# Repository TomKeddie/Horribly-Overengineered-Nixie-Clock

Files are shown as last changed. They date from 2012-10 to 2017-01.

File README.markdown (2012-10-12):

# Horribly Overengineered Nixie Clock

This is a "horribly overengineered" Nixie clock as the "clock" part could have been achieved far cheaper
and far easier. However, the end result (that there is an actual physical clock) is merely a side effect;
the main motivation for me was to use this project as means to learn something new. To this end, I've used
a fairly expensive ARM microcontroller and the mainboard also includes both USB and Ethernet connectivity.

There are two PCBs in this project: a driver board housing two Nixie tubes with their corresponding drivers
and a mainboard with the uC and other circuitry. The driver board is designed to fit into the 5x5 cm limit
and the mainboard fits the 5x10 cm limit of ITead Studio/Seeed Studio. A full kit with 6 digits would consist
of one mainboard PCB and three driver PCBs.

(The firmware will appear here as soon as there is something usable.)

## BOM

The key components are:

  * ИН-12 Nixie tubes
  * К155ИД1 drivers
  * [Taylor Electronics HVPS-V](http://www.tayloredge.com/storefront/SmartNixie/PSU/index.html) high voltage power supply
  * [NXP LPC1764](http://ics.nxp.com/products/lpc1000/lpc17xx/~LPC1764/) ARM Cortex-M3 microcontroller

Rev A:
  * [Micrel KSZ8001L](http://www.micrel.com/page.do?page=product-info/fastether_trans.jsp) Ethernet PHY

Rev B:
 
  * [Micrel MIC4680](http://micrel.com/index.php/en/component/joodb/article/41-step-down-internal-switches/24-mic4680.html) buck regulator
  * [Micrel KSZ8051RNL](http://micrel.com/index.php/en/component/joodb/article/13-phys/10-ksz8051rnl.html) Ethernet PHY

## Truth table for module

Note that for ease of routing the truth table doesn't match 74(1)41/K155ID1:

<table>
  <tr><th>Num</th> <th>A</th> <th>B</th> <th>C</th> <th>D</th></tr>
  <tr><td>0</td><td>H</td><td>L</td><td>H</td><td>L</td></tr>
  <tr><td>1</td><td>H</td><td>L</td><td>L</td><td>H</td></tr>
  <tr><td>2</td><td>L</td><td>H</td><td>H</td><td>L</td></tr>
  <tr><td>3</td><td>H</td><td>H</td><td>H</td><td>L</td></tr>
  <tr><td>4</td><td>L</td><td>H</td><td>L</td><td>L</td></tr>
  <tr><td>5</td><td>H</td><td>H</td><td>L</td><td>L</td></tr>
  <tr><td>6</td><td>L</td><td>L</td><td>H</td><td>L</td></tr>
  <tr><td>7</td><td>L</td><td>L</td><td>L</td><td>H</td></tr>
  <tr><td>8</td><td>L</td><td>L</td><td>L</td><td>L</td></tr>
  <tr><td>9</td><td>H</td><td>L</td><td>L</td><td>L</td></tr>
</table>

## Errata for Rev A

  * SWDCLK is not routed to JTAG. Oops.
  * P0[28] does not have an external pull-up. Note to self: read the datasheet. Twice.
  * Either LPC parts in general [do not like the cheap-o "tube" 32.768 kHz crystals](http://mbed.org/forum/mbed/topic/1110/) or 
    I can't figure out the proper load capacitance without an actual datasheet. Will switch to a SMD crystal if Rev B ever comes.
  * `RESET` was very flaky until I soldered a 1 μF capacitor to GND across it.
  * Ethernet chip went up in smoke. Oops.
  * No proper way to mount a heatsink on the 7805, and the HVPS audibly complains about low voltages that keep the heat of '05 in check.

## Changelog for Rev B

  * SWDCLK is properly routed.
  * Added a switch-mode 5V power supply based on [Micrel MIC4680](http://micrel.com/index.php/en/component/joodb/article/41-step-down-internal-switches/24-mic4680.html)
  * Changed the Ethernet PHY to [Micrel KSZ8051RNL](http://micrel.com/index.php/en/component/joodb/article/13-phys/10-ksz8051rnl.html)
  * Changed the RTC crystal
  * Added power and USB LEDs.

## Errata for Rev B

  * RTC still won't oscillate. I haven't given up on it yet, as I have a proper datasheet now.
  * Ethernet still doesn't work, but at least didn't go up in smoke. Might just be my bad soldering or a software issue.

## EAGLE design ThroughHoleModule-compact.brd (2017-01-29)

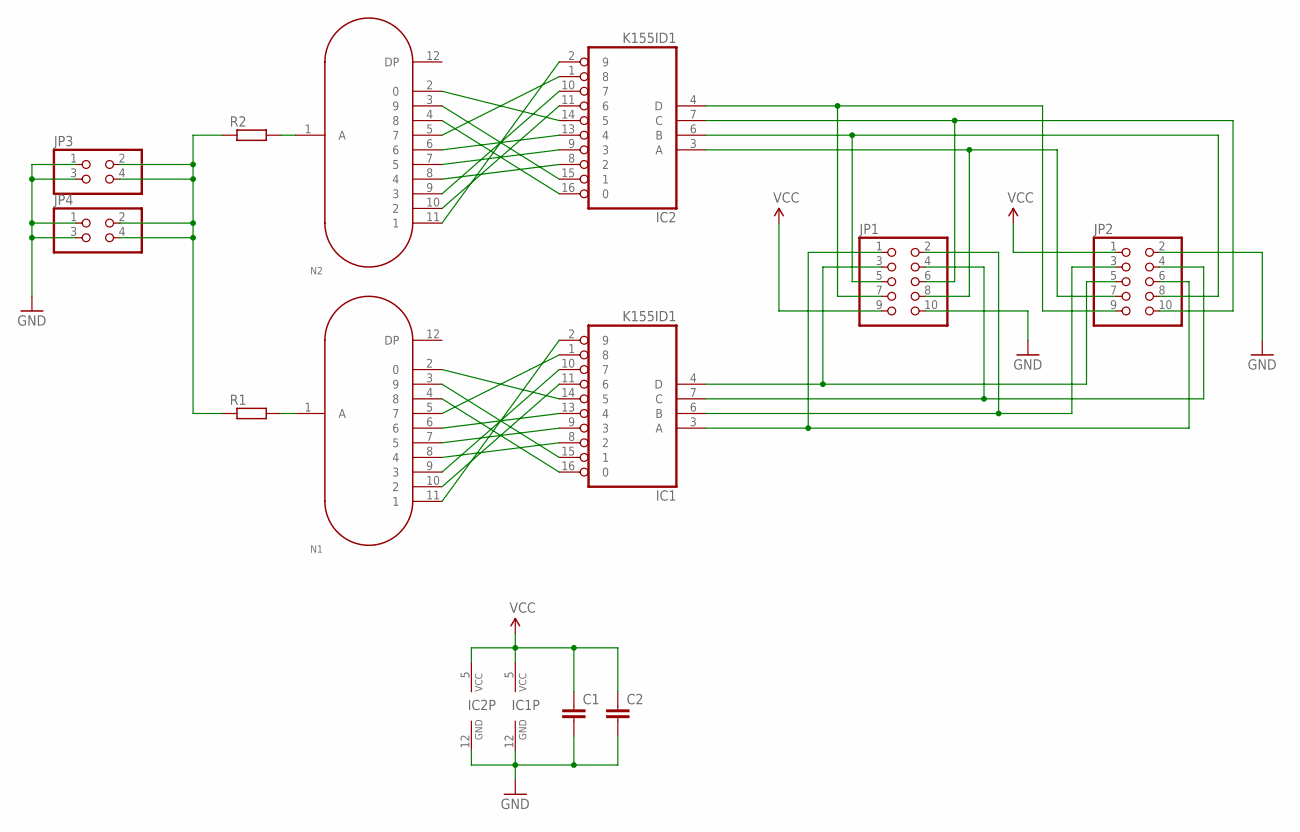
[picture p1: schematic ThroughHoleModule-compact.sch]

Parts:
C1, C2: C-EU050-030X075; C050-030X075
IC1, IC2: K155ID1; DIL16
JP1, JP2: PINHD-2X5; 2X05
JP3, JP4: PINHD-2X2; 2X02
N1, N2: IN-12B; IN-12
R1, R2: R-EU_0207/10; 0207/10

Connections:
1A: IC1.3 (A), JP1.1, JP2.6
1B: IC1.6 (B), JP1.2, JP2.3
1C: IC1.7 (C), JP1.4, JP2.4
1D: IC1.4 (D), JP1.3, JP2.5
2A: IC2.3 (A), JP1.8, JP2.7
2B: IC2.6 (B), JP1.5, JP2.8
2C: IC2.7 (C), JP1.6, JP2.10
2D: IC2.4 (D), JP1.7, JP2.9
GND: C1.2, C2.2, IC1.12 (GND), IC2.12 (GND), JP1.10, JP2.2, JP3.1, JP3.3, JP4.1, JP4.3
HV: JP3.2, JP3.4, JP4.2, JP4.4, R1.1, R2.1
unnamed: IC2.1 (8), N2.5 (7)
unnamed: IC2.13 (4), N2.6
unnamed: IC1.1 (8), N1.5 (7)
unnamed: IC1.13 (4), N1.6
unnamed: IC2.9 (3), N2.7 (5)
unnamed: IC2.8 (2), N2.8 (4)
unnamed: IC2.10 (7), N2.9 (3)
unnamed: IC2.11 (6), N2.10 (2)
unnamed: IC2.2 (9), N2.11 (1)
unnamed: IC2.14 (5), N2.2 (0)
unnamed: IC2.15 (1), N2.3 (9)
unnamed: IC2.16 (0), N2.4 (8)
unnamed: IC1.2 (9), N1.11 (1)
unnamed: IC1.11 (6), N1.10 (2)
unnamed: IC1.10 (7), N1.9 (3)
unnamed: IC1.8 (2), N1.8 (4)
unnamed: IC1.9 (3), N1.7 (5)
unnamed: IC1.16 (0), N1.4 (8)
unnamed: IC1.15 (1), N1.3 (9)
unnamed: IC1.14 (5), N1.2 (0)
unnamed: N1.1 (A), R1.2
unnamed: N2.1 (A), R2.2
VCC: C1.1, C2.1, IC1.5 (VCC), IC2.5 (VCC), JP1.9, JP2.1

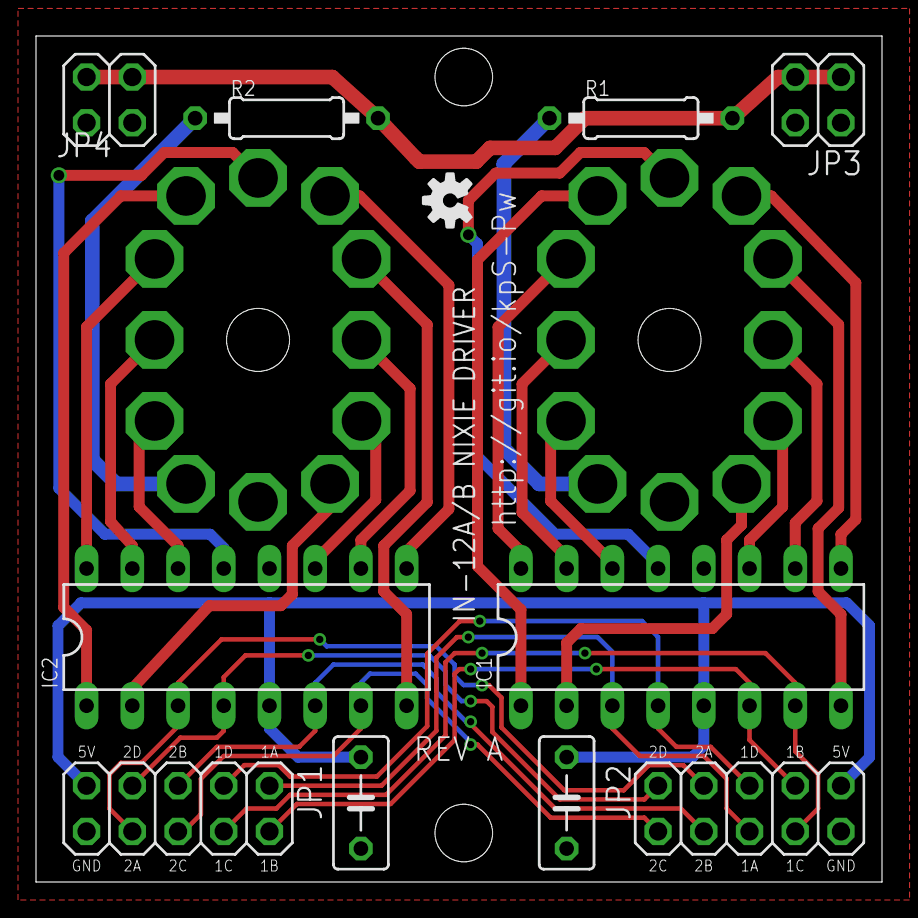
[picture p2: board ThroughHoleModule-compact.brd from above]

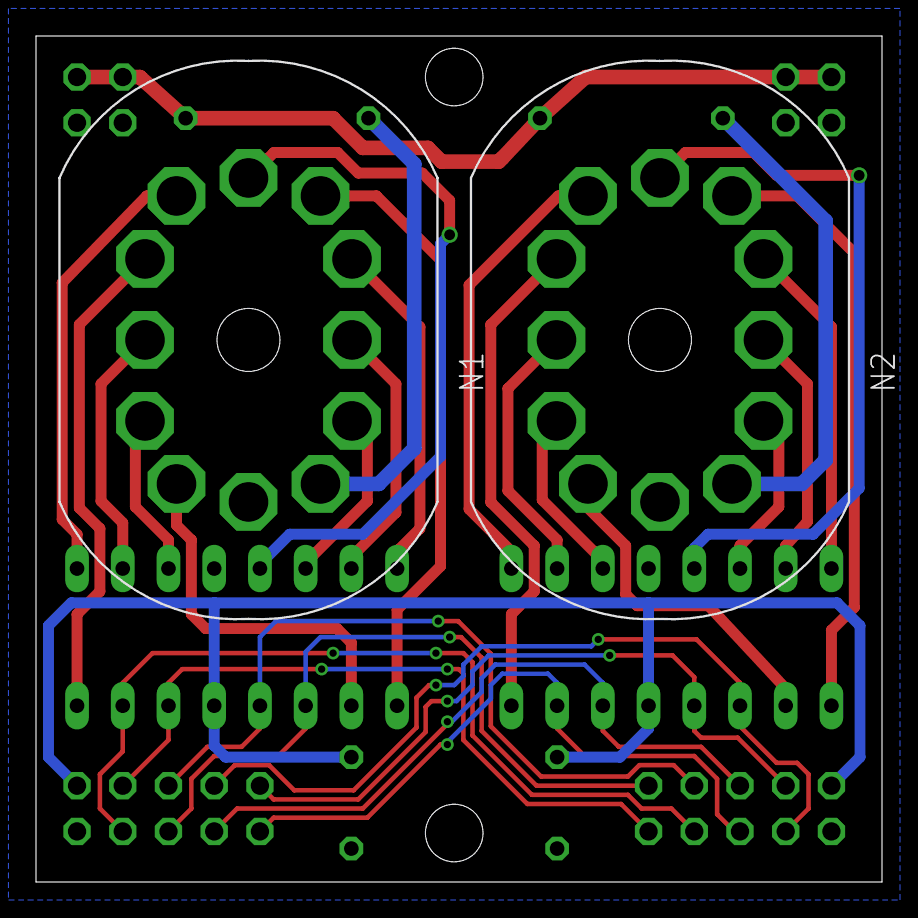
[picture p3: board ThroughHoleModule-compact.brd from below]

Board: 2 copper layers, 47.0 x 47.0 mm, 13 parts (2 on the bottom side), 33 nets.

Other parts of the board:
U$1: OSHW-LOGO-S

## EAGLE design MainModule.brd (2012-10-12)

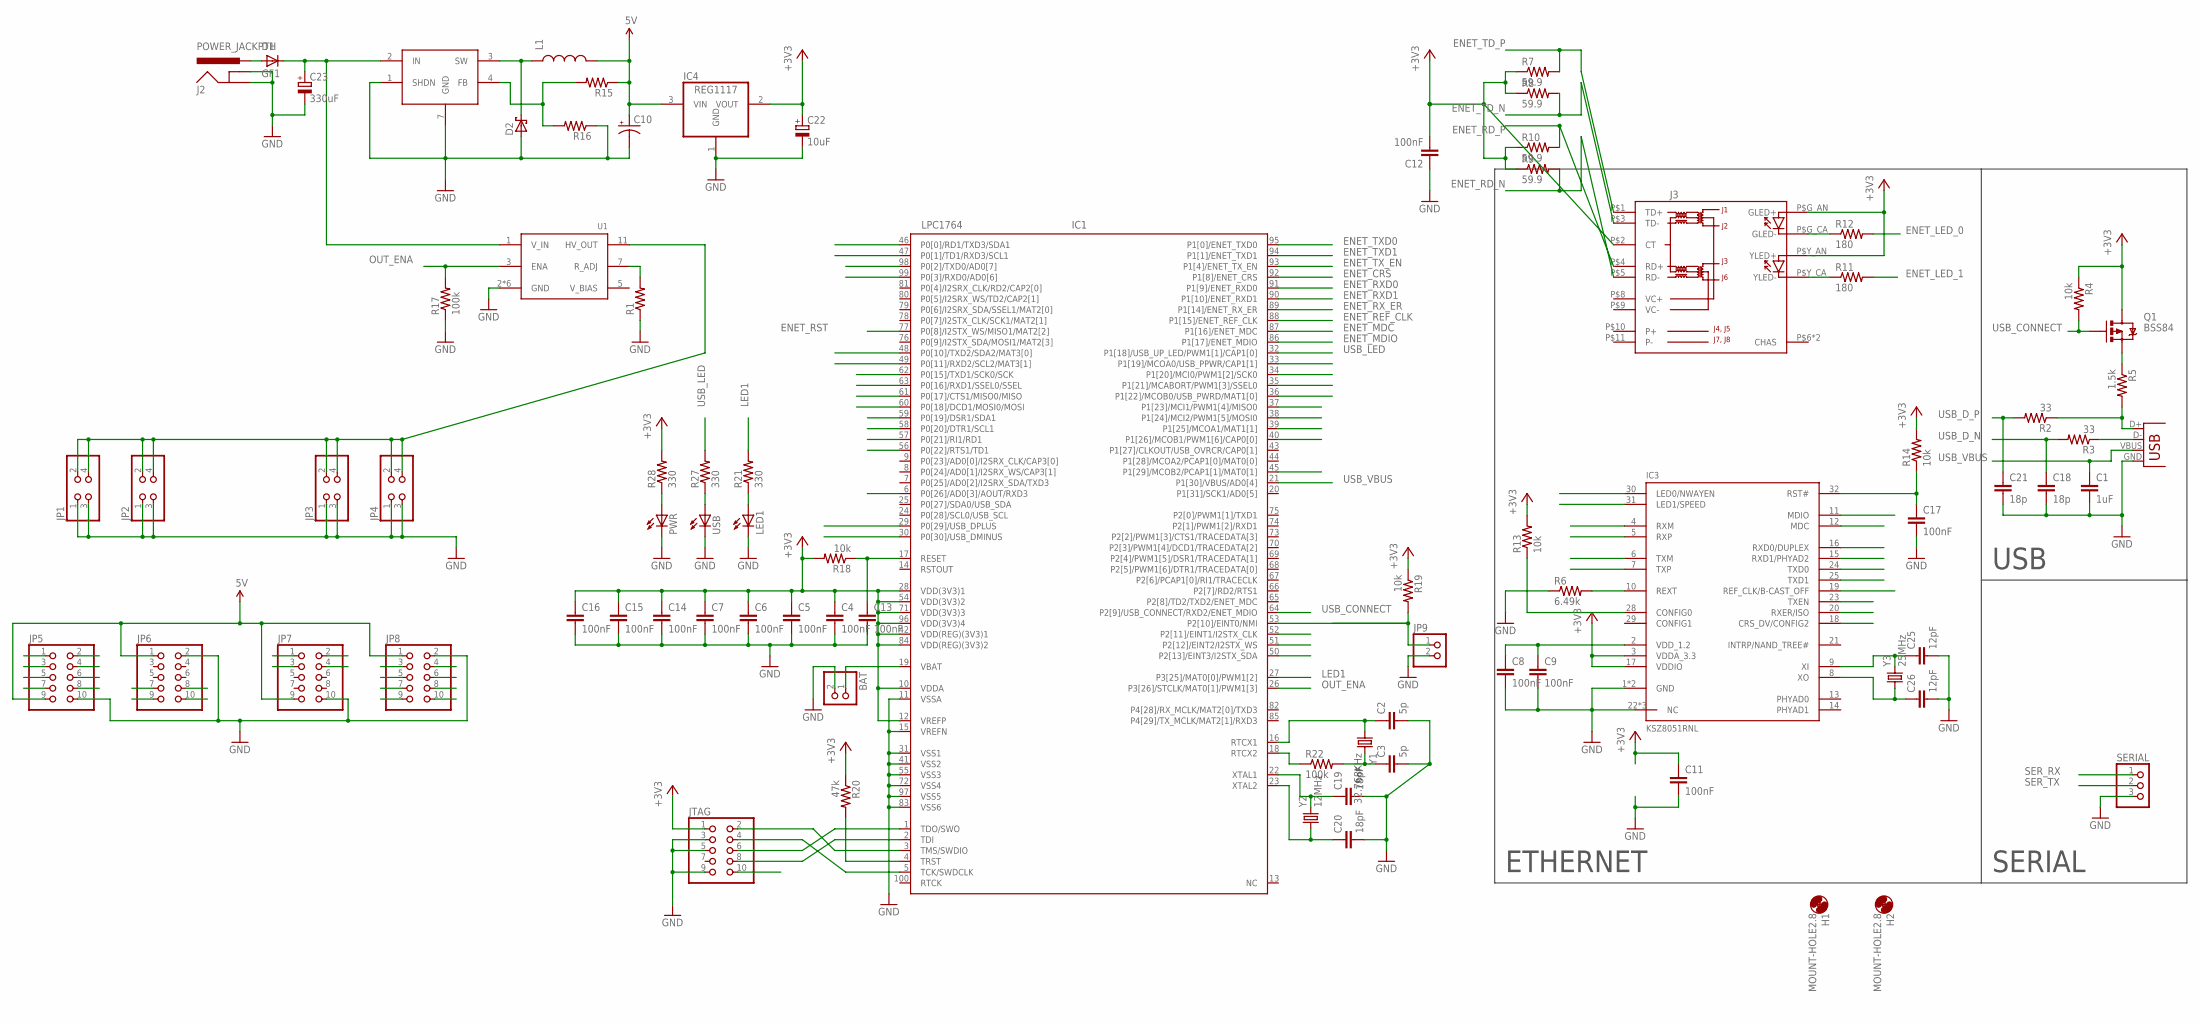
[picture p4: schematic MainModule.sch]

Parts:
BAT: PINHD-1X2; 1X02
C1: 1uF; 0805
C2, C3: 5p; 0805
C4, C5, C6, C7, C8, C9, C11, C12, C13, C14, C15, C16, C17: 100nF; 0805
C10: CAP_POLD; PANASONIC_D
C18, C21: 18p; 0805
C19, C20: 18pF; 0805
C22: 10uF; PANASONIC_B
C23: 330uF; E3,5-8
C25, C26: 12pF; 0805
D1: GF1; SMA-DO214AC
D2: SCHOTTKY-DIODESMD; SMB
H1, H2: MOUNT-HOLE2.8; 2,8
IC1: LPC1764; LQFP100-14X14
IC2: MIC4680; SOIC-8
IC3: KSZ8051RNL; QFN-32
IC4: REG1117; SOT223
J1: USBSMD; USB-MINIB
J2: POWER_JACKPTH; POWER_JACK_PTH
J3: MAGJACK-SI-52008; MAGJACK-SI-52008-F
JP1, JP2, JP3, JP4: PINHD-2X2; 2X02
JP5, JP6, JP7, JP8: PINHD-2X5; 2X05
JP9: PINHD-1X2; 1X02
JTAG: PINHD-2X5; 2X05
L1: INDUCTORB; INDUCTOR-MCSDC0906
LED1: LEDCHIP-LED0805; CHIP-LED0805
PWR: LEDCHIP-LED0805; CHIP-LED0805
Q1: BSS84; SOT23-3
R1, R15, R16: RESISTOR0805-RES; 0805
R2, R3: 33; 0805
R4, R13, R14, R18, R19: 10k; 0805
R5: 1.5k; 0805
R6: 6.49k; 0805
R7, R8, R9, R10: 59.9; 0805
R11, R12: 180; 0805
R17, R22: 100k; 0805
R20: 47k; 0805
R21, R27, R28: 330; 0805
SERIAL: PINHD-1X3; 1X03
U1: HVPS-1363
USB: LEDCHIP-LED0805; CHIP-LED0805
Y1: 32.768KHz; 85SMX
Y2: 12MHz; TXC-7A
Y3: 25MHz; TXC-7A

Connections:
5V: C10.+, IC4.3 (VIN), JP5.9, JP6.1, JP7.9, JP8.1, L1.4 (2), R15.1
+3V3: C4.1, C5.1, C6.1, C7.1, C11.1, C12.2, C14.1, C15.1, C16.1, C22.+, IC1.10 (VDDA), IC1.12 (VREFP), IC1.28 (VDD(3V3)1), IC1.42 (VDD(REG)(3V3)1), IC1.54 (VDD(3V3)2), IC1.71 (VDD(3V3)3), IC1.84 (VDD(REG)(3V3)2), IC1.96 (VDD(3V3)4), IC3.3 (VDDA_3.3), IC3.17 (VDDIO), IC4.2 (VOUT), J3.P$2 (CT), J3.P$G_AN (GLED+), J3.P$Y_AN (YLED+), JTAG.1, Q1.3 (D), R4.1, R7.1, R8.1, R9.1, R10.1, R13.2, R14.2, R18.2, R19.1, R20.1, R28.2
BTN1: IC1.45 (P1[29]/MCOB2/PCAP1[1]/MAT0[1])
ENET_CRS: IC1.92 (P1[8]/ENET_CRS), IC3.18 (CRS_DV/CONFIG2)
ENET_LED_0: IC3.30 (LED0/NWAYEN), R12.2
ENET_LED_1: IC3.31 (LED1/SPEED), R11.2
ENET_MDC: IC1.87 (P1[16]/ENET_MDC), IC3.12 (MDC)
ENET_MDIO: IC1.86 (P1[17]/ENET_MDIO), IC3.11 (MDIO)
ENET_RD_N: IC3.4 (RXM), J3.P$5 (RD-), R9.2
ENET_RD_P: IC3.5 (RXP), J3.P$4 (RD+), R10.2
ENET_REF_CLK: IC1.88 (P1[15]/ENET_REF_CLK), IC3.19 (REF_CLK/B-CAST_OFF)
ENET_RST: C17.1, IC1.77 (P0[8]/I2STX_WS/MISO1/MAT2[2]), IC3.32 (RST#), R14.1
ENET_RXD0: IC1.91 (P1[9]/ENET_RXD0), IC3.16 (RXD0/DUPLEX)
ENET_RXD1: IC1.90 (P1[10]/ENET_RXD1), IC3.15 (RXD1/PHYAD2)
ENET_RX_ER: IC1.89 (P1[14]/ENET_RX_ER), IC3.20 (RXER/ISO)
ENET_TD_N: IC3.6 (TXM), J3.P$3 (TD-), R8.2
ENET_TD_P: IC3.7 (TXP), J3.P$1 (TD+), R7.2
ENET_TXD0: IC1.95 (P1[0]/ENET_TXD0), IC3.24 (TXD0)
ENET_TXD1: IC1.94 (P1[1]/ENET_TXD1), IC3.25 (TXD1)
ENET_TX_EN: IC1.93 (P1[4]/ENET_TX_EN), IC3.23 (TXEN)
GND: BAT.2, C1.2, C2.2, C3.2, C4.2, C5.2, C6.2, C7.2, C8.2, C9.2, C10.-, C11.2, C12.1, C13.2, C14.2, C15.2, C16.2, C17.2, C18.2, C19.2, C20.2, C21.2, C22.-, C23.-, C25.2, C26.2, D2.A, IC1.11 (VSSA), IC1.15 (VREFN), IC1.31 (VSS1), IC1.41 (VSS2), IC1.55 (VSS3), IC1.72 (VSS4), IC1.83 (VSS6), IC1.97 (VSS5), IC2.1 (SHDN), IC2.5 (GND), IC2.6 (GND), IC2.7 (GND), IC2.8 (GND), IC3.1 (GND), IC3.22 (NC), IC3.26 (NC), IC3.27 (NC), IC3.EP (GND), IC4.1 (GND), J1.GND, J2.GND, J2.GNDBREAK, JP1.1, JP1.3, JP2.1, JP2.3, JP3.1, JP3.3, JP4.1, JP4.3, JP5.10, JP6.2, JP7.10, JP8.2, JP9.2, JTAG.3, JTAG.5, JTAG.9, LED1.C, PWR.C, R1.1, R6.1, R16.1, R17.1, SERIAL.3, U1.2 (GND), U1.4 (GND), U1.6 (GND), U1.8 (GND), U1.9 (GND), U1.10 (GND), USB.C
HV: JP1.2, JP1.4, JP2.2, JP2.4, JP3.2, JP3.4, JP4.2, JP4.4, U1.11 (HV_OUT)
JP5_1: IC1.33 (P1[19]/MCOA0/USB_PPWR/CAP1[1]), JP5.1
JP5_2: IC1.34 (P1[20]/MCI0/PWM1[2]/SCK0), JP5.2
JP5_3: IC1.35 (P1[21]/MCABORT/PWM1[3]/SSEL0), JP5.3
JP5_4: IC1.36 (P1[22]/MCOB0/USB_PWRD/MAT1[0]), JP5.4
JP5_5: IC1.37 (P1[23]/MCI1/PWM1[4]/MISO0), JP5.5
JP5_6: IC1.38 (P1[24]/MCI2/PWM1[5]/MOSI0), JP5.6
JP5_7: IC1.39 (P1[25]/MCOA1/MAT1[1]), JP5.7
JP5_8: IC1.40 (P1[26]/MCOB1/PWM1[6]/CAP0[0]), JP5.8
JP6_7: IC1.46 (P0[0]/RD1/TXD3/SDA1), JP6.7
JP6_8: IC1.48 (P0[10]/TXD2/SDA2/MAT3[0]), JP6.8
JP6_9: IC1.47 (P0[1]/TD1/RXD3/SCL1), JP6.9
JP6_10: IC1.49 (P0[11]/RXD2/SCL2/MAT3[1]), JP6.10
JP7_5: IC1.52 (P2[11]/EINT1/I2STX_CLK), JP7.1
JP7_6: IC1.50 (P2[13]/EINT3/I2STX_SDA), JP7.2
JP7_7: IC1.53 (P2[10]/EINT0/NMI), JP7.3, JP9.1, R19.2
JP7_8: IC1.51 (P2[12]/EINT2/I2STX_WS), JP7.4
JP8_3: IC1.57 (P0[21]/RI1/RD1), JP8.3
JP8_4: IC1.56 (P0[22]/RTS1/TD1), JP8.4
JP8_5: IC1.59 (P0[19]/DSR1/SDA1), JP8.5
JP8_6: IC1.58 (P0[20]/DTR1/SCL1), JP8.6
JP8_7: IC1.61 (P0[17]/CTS1/MISO0/MISO), JP8.7
JP8_8: IC1.60 (P0[18]/DCD1/MOSI0/MOSI), JP8.8
JP8_9: IC1.63 (P0[16]/RXD1/SSEL0/SSEL), JP8.9
JP8_10: IC1.62 (P0[15]/TXD1/SCK0/SCK), JP8.10
LED1: IC1.27 (P3[25]/MAT0[0]/PWM1[2]), R21.2
unnamed: R1.2, U1.7 (R_ADJ)
unnamed: C23.+, D1.K (C), IC2.2 (IN), U1.1 (V_IN)
unnamed: J1.D+, R2.1, R5.2
unnamed: R27.1, USB.A
unnamed: J1.D-, R3.1
unnamed: Q1.2 (S), R5.1
unnamed: PWR.A, R28.1
unnamed: C2.1, IC1.16 (RTCX1), Y1.1
unnamed: C3.1, R22.2, Y1.4 (2)
unnamed: IC3.10 (REXT), R6.2
unnamed: J3.P$G_CA (GLED-), R12.1
unnamed: C25.1, IC3.9 (XI), Y3.P$2 (2)
unnamed: J3.P$Y_CA (YLED-), R11.1
unnamed: C26.1, IC3.8 (XO), Y3.P$1 (1)
unnamed: IC1.4 (TRST), R20.2
unnamed: C8.1, C9.1, IC3.2 (VDD_1.2)
unnamed: C20.1, IC1.23 (XTAL2), Y2.P$1 (1)
unnamed: C19.1, IC1.22 (XTAL1), Y2.P$2 (2)
unnamed: D1.A, J2.PWR
unnamed: BAT.1, IC1.19 (VBAT)
unnamed: IC3.28 (CONFIG0), R13.1
unnamed: LED1.A, R21.1
unnamed: IC2.4 (FB), R15.2, R16.2
unnamed: D2.C, IC2.3 (SW), L1.1
unnamed: IC1.18 (RTCX2), R22.1
OUT_ENA: IC1.26 (P3[26]/STCLK/MAT0[1]/PWM1[3]), R17.2, U1.3 (ENA)
RESET: C13.1, IC1.17 (RESET), JTAG.10, R18.1
RSTOUT: IC1.6 (P0[26]/AD0[3]/AOUT/RXD3)
SER_RX: IC1.99 (P0[3]/RXD0/AD0[6]), SERIAL.1
SER_TX: IC1.98 (P0[2]/TXD0/AD0[7]), SERIAL.2
SWDCLK: IC1.5 (TCK/SWDCLK), JTAG.4
SWDIO: IC1.3 (TMS/SWDIO), JTAG.2
SWO: IC1.1 (TDO/SWO), JTAG.6
TDI: IC1.2 (TDI), JTAG.8
USB_CONNECT: IC1.64 (P2[9]/USB_CONNECT/RXD2/ENET_MDIO), Q1.1 (G), R4.2
USB_D_N: C18.1, IC1.30 (P0[30]/USB_DMINUS), R3.2
USB_D_P: C21.1, IC1.29 (P0[29]/USB_DPLUS), R2.2
USB_LED: IC1.32 (P1[18]/USB_UP_LED/PWM1[1]/CAP1[0]), R27.2
USB_VBUS: C1.1, IC1.21 (P1[30]/VBUS/AD0[4]), J1.VBUS

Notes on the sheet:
USB
ETHERNET
SERIAL

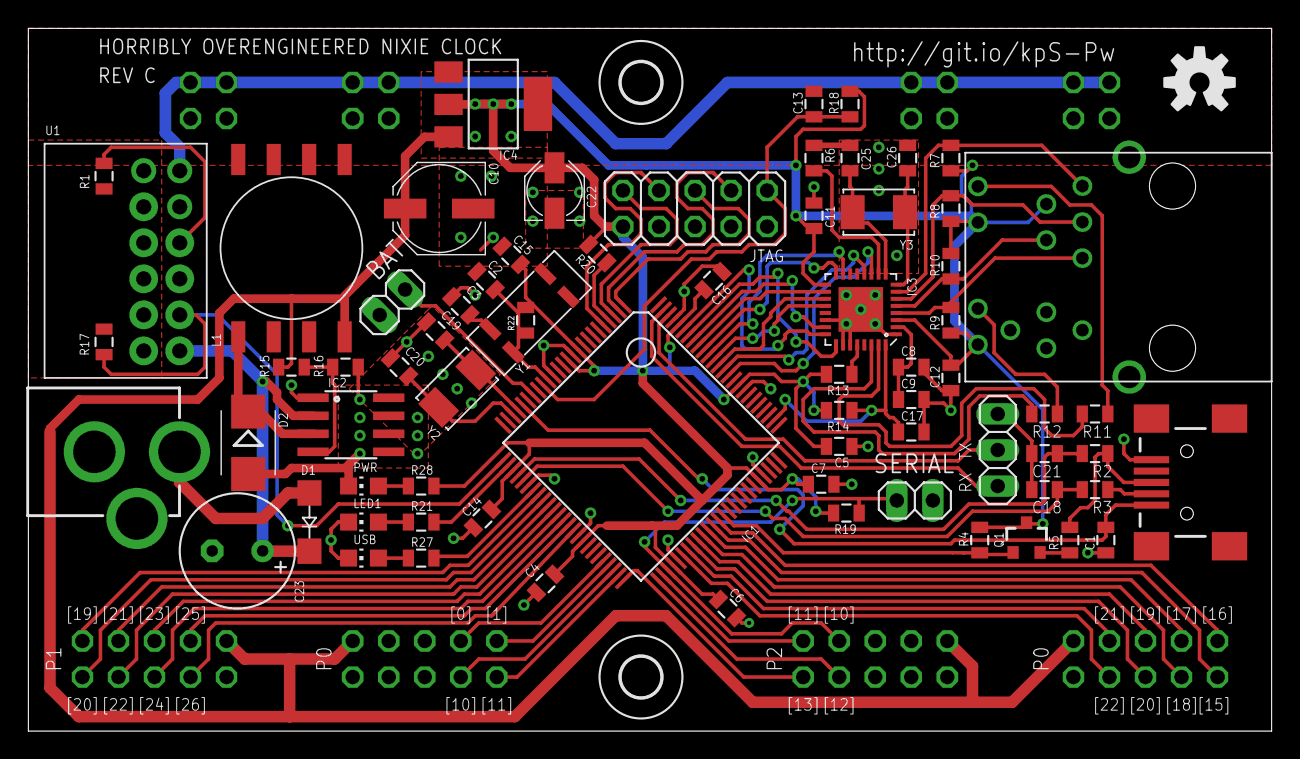
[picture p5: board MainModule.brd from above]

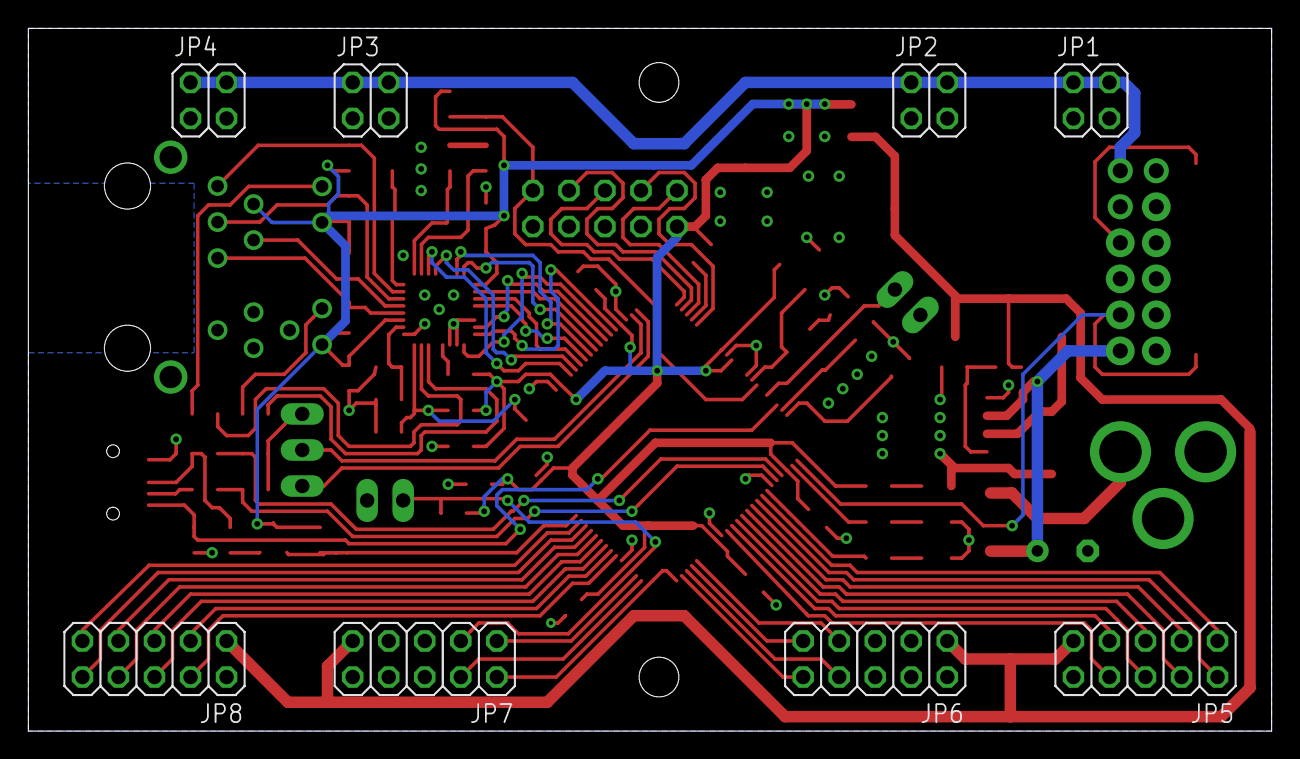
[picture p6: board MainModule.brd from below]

Board: 2 copper layers, 87.6 x 49.5 mm, 82 parts (8 on the bottom side), 84 nets.

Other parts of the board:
U$1: OSHW-LOGO-M

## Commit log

2012-04-07 RESET wants a capacitor
2012-10-12 Rev B
    [MainModule.brd, MainModule.sch]
2017-01-29 Enlarged IN-12 mounting holes
    [ThroughHoleModule-compact.brd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]
2017-01-29 Reduced size for panelisation
    [ThroughHoleModule-compact.brd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]

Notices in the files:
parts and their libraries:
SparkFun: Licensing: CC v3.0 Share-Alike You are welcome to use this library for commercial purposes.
